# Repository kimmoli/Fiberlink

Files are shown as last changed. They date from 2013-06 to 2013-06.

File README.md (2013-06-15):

Fiberlink
=========

USB <-> 1000µm Fiber <-> RS-232 <-> RS-485

USB <-> RS232
SJ6, SJ7

USB <-> RS485
SJ10, SJ11, SJ15

USB <-> FIBER
SJ3, SJ5

RS232 <-> RS485
SJ12, SJ13, SJ14

RS232 <-> FIBER
SJ2, SJ4

FIBER <-> RS485
SJ8, SJ9, SJ14

SJ2 FIBER RX TO RS232
SJ3 FIBER RX TO USB
SJ4 RS232 RX TO FIBER
SJ5 USB RX TO FIBER
SJ6 USB RX TO RS232
SJ7 RS232 RX TO USB
SJ8 RS485 RX TO FIBER
SJ9 FIBER RX TO RS485
SJ10 RS485 RX TO USB
SJ11 USB RX TO RS485
SJ12 RS232 RX TO RS485
SJ13 RS485 RX TO RS232
SJ14 CARRIER SENSE TO RX485 TXEN
SJ15 USB TXEN TO RS485 TXEN

SJ17 FTDI POWER SELECT

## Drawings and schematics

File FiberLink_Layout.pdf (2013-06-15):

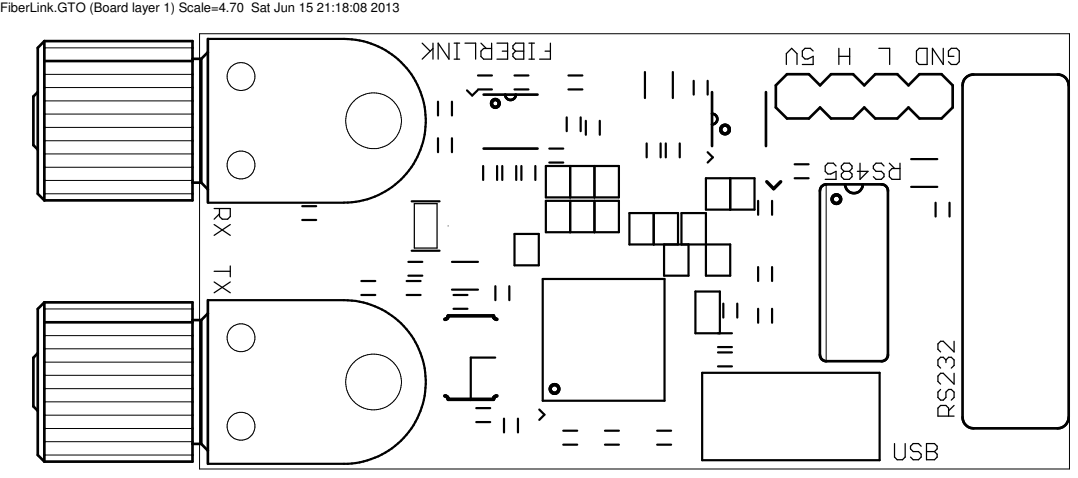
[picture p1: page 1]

FiberLink.GTO (Board layer 1) Scale=4.70 Sat Jun 15 21:18:08 2013

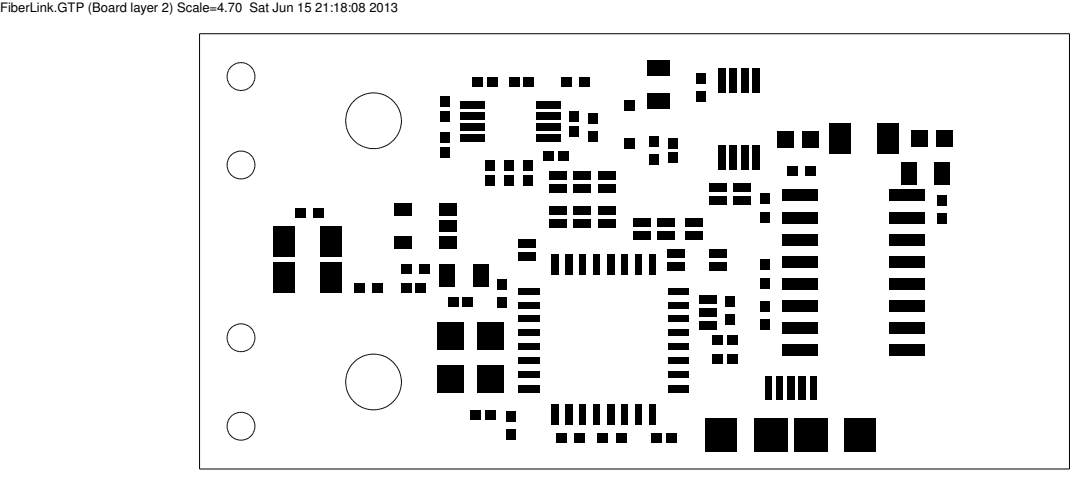
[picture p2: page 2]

FiberLink.GTP (Board layer 2) Scale=4.70 Sat Jun 15 21:18:08 2013

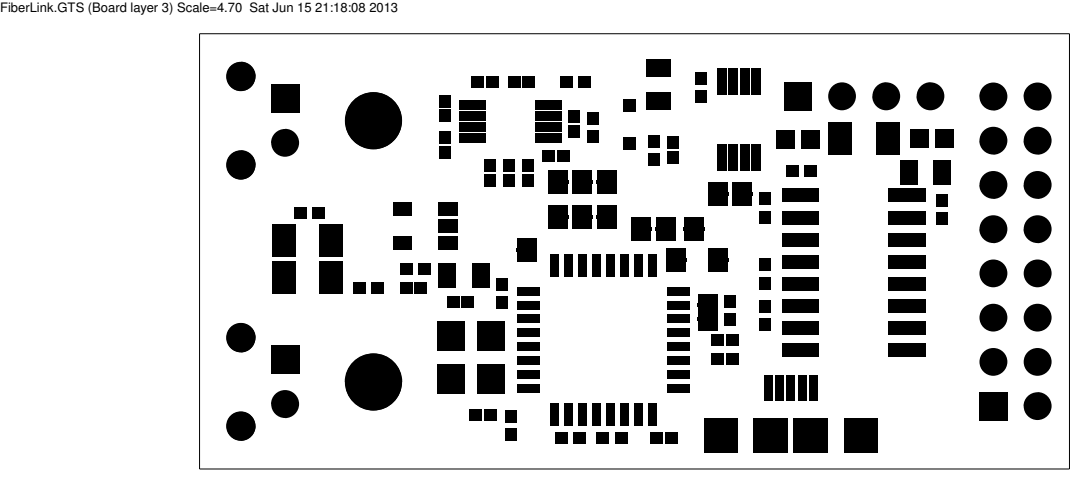
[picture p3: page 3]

FiberLink.GTS (Board layer 3) Scale=4.70 Sat Jun 15 21:18:08 2013

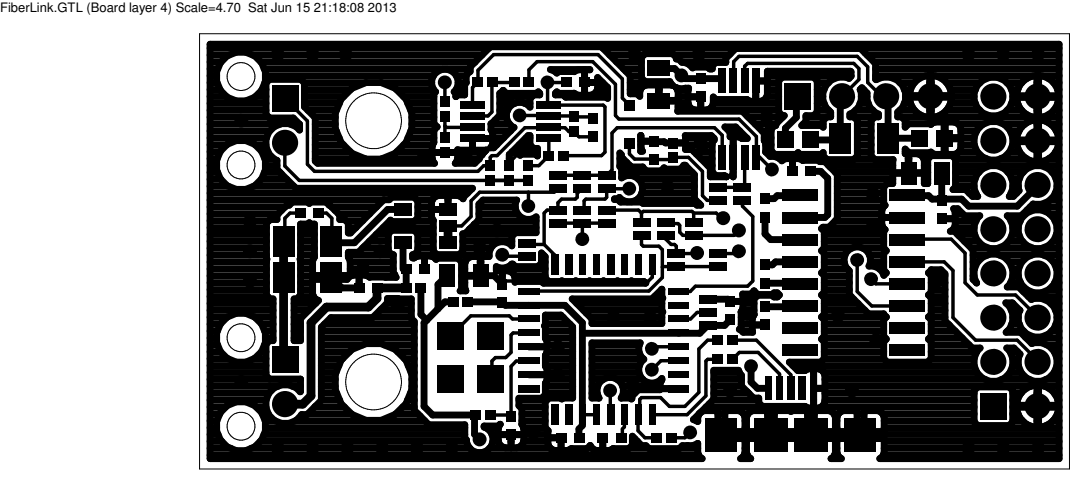
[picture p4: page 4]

FiberLink.GTL (Board layer 4) Scale=4.70 Sat Jun 15 21:18:08 2013

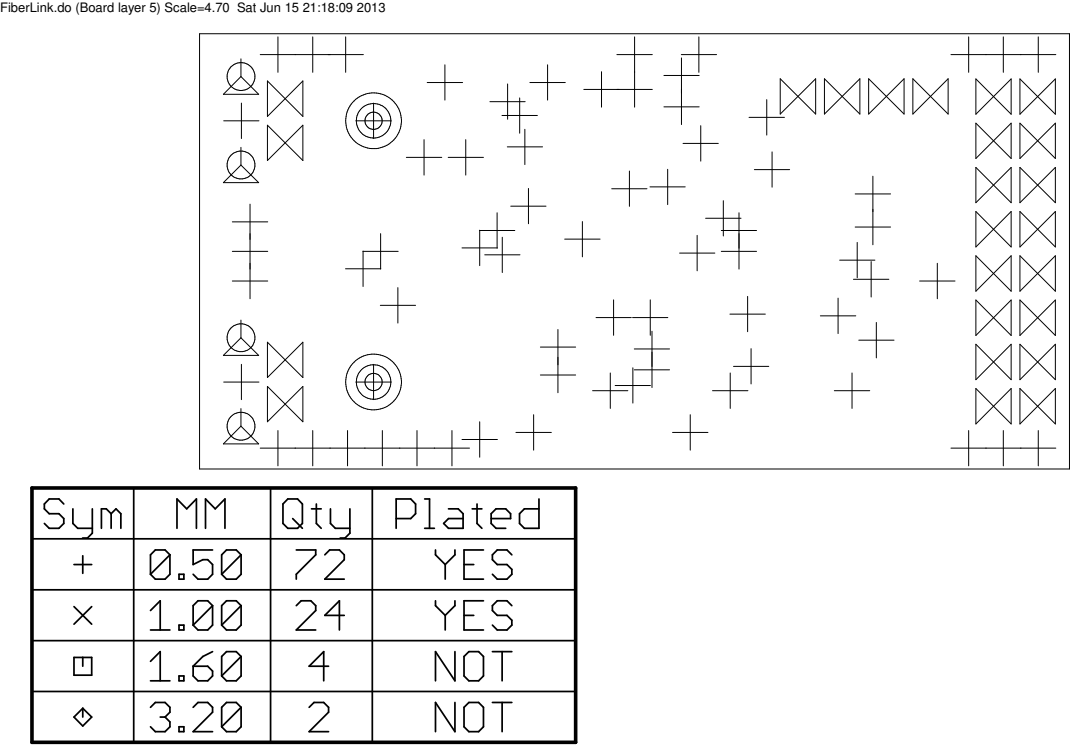
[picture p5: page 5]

FiberLink.do (Board layer 5) Scale=4.70 Sat Jun 15 21:18:09 2013

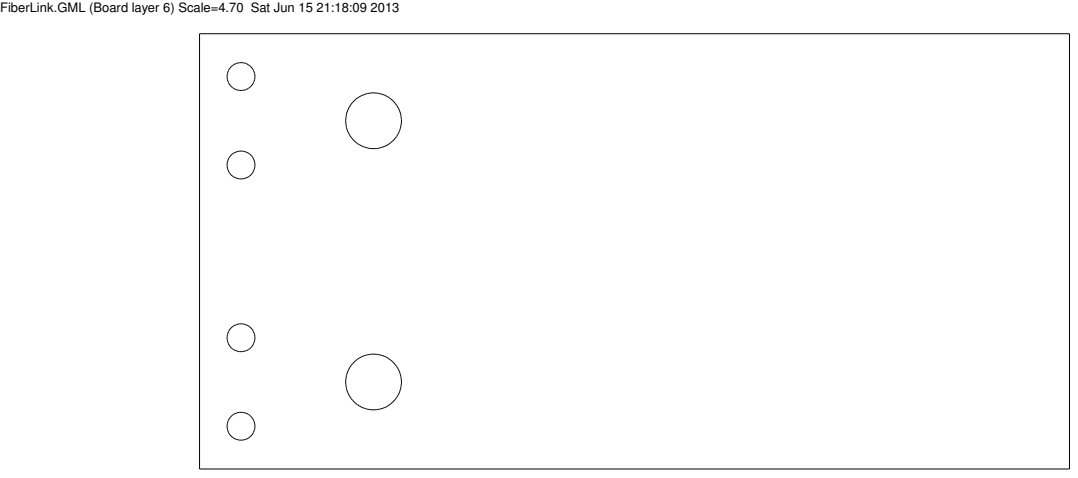
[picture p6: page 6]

FiberLink.GML (Board layer 6) Scale=4.70 Sat Jun 15 21:18:09 2013

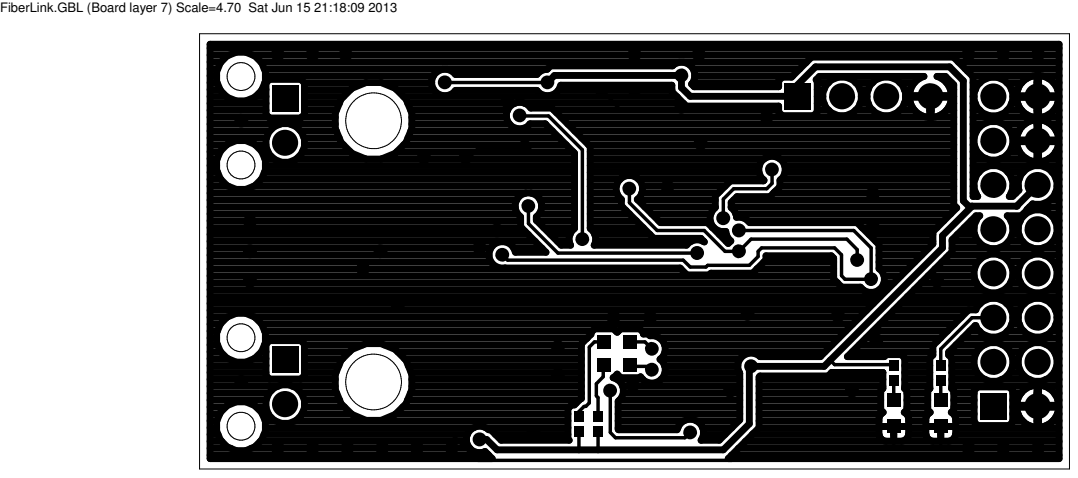
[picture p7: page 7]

FiberLink.GBL (Board layer 7) Scale=4.70 Sat Jun 15 21:18:09 2013

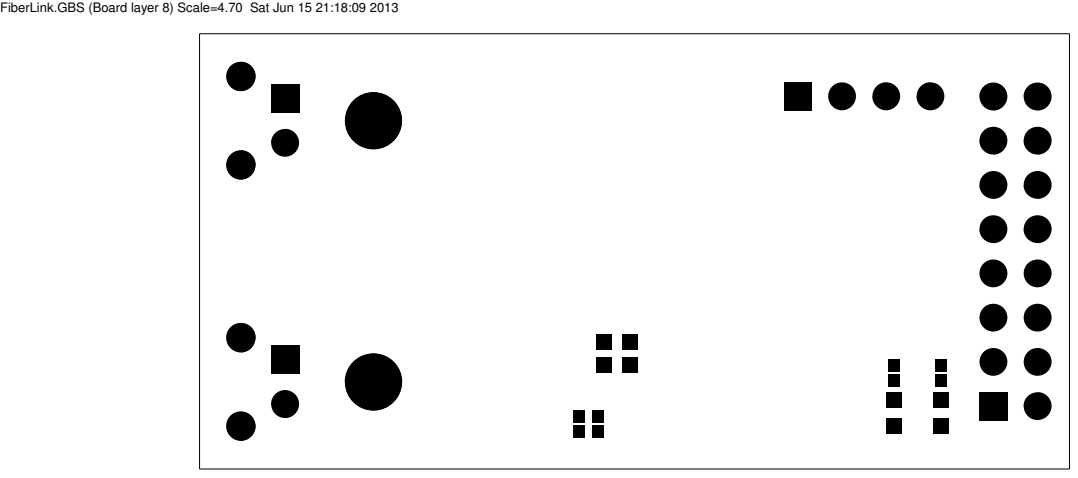
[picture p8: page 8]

FiberLink.GBS (Board layer 8) Scale=4.70 Sat Jun 15 21:18:09 2013

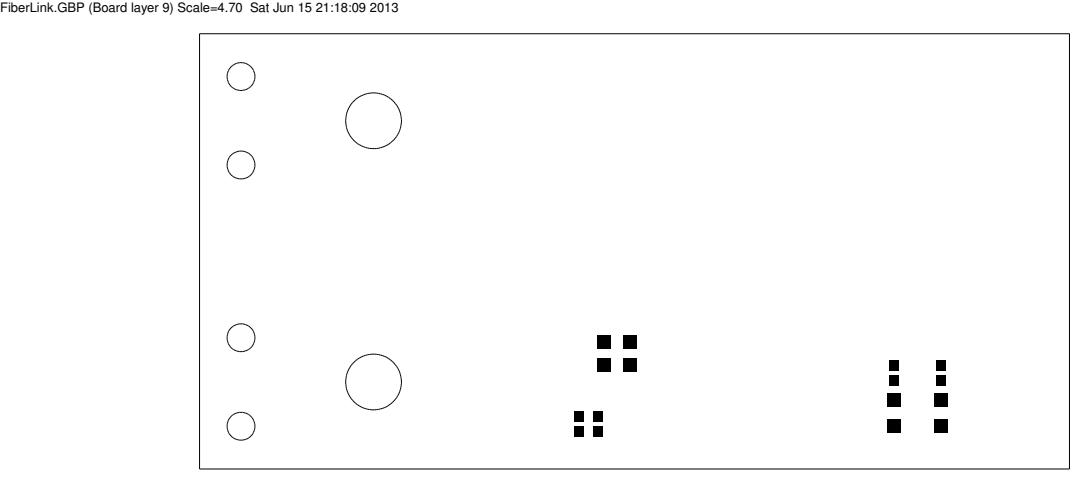
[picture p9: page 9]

FiberLink.GBP (Board layer 9) Scale=4.70 Sat Jun 15 21:18:09 2013

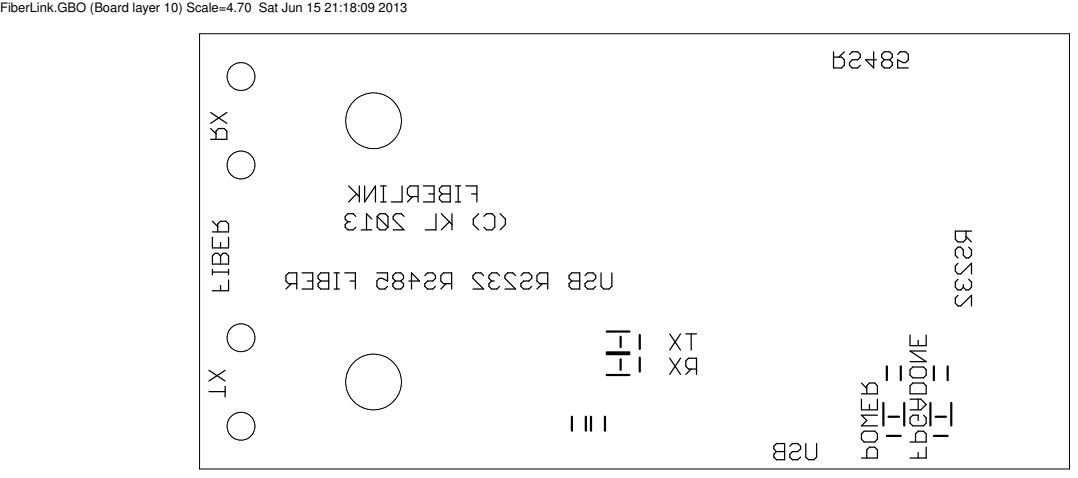
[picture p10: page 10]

FiberLink.GBO (Board layer 10) Scale=4.70 Sat Jun 15 21:18:09 2013

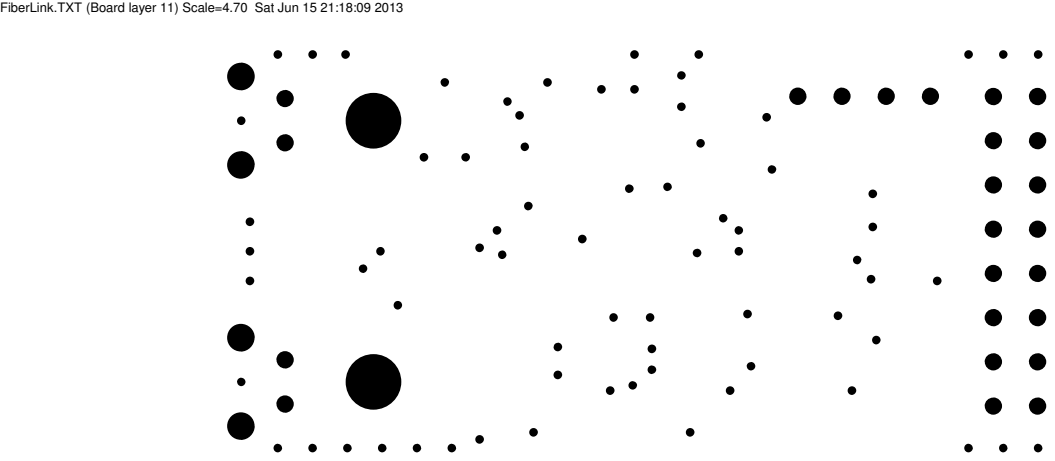
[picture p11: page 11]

FiberLink.TXT (Board layer 11) Scale=4.70 Sat Jun 15 21:18:09 2013

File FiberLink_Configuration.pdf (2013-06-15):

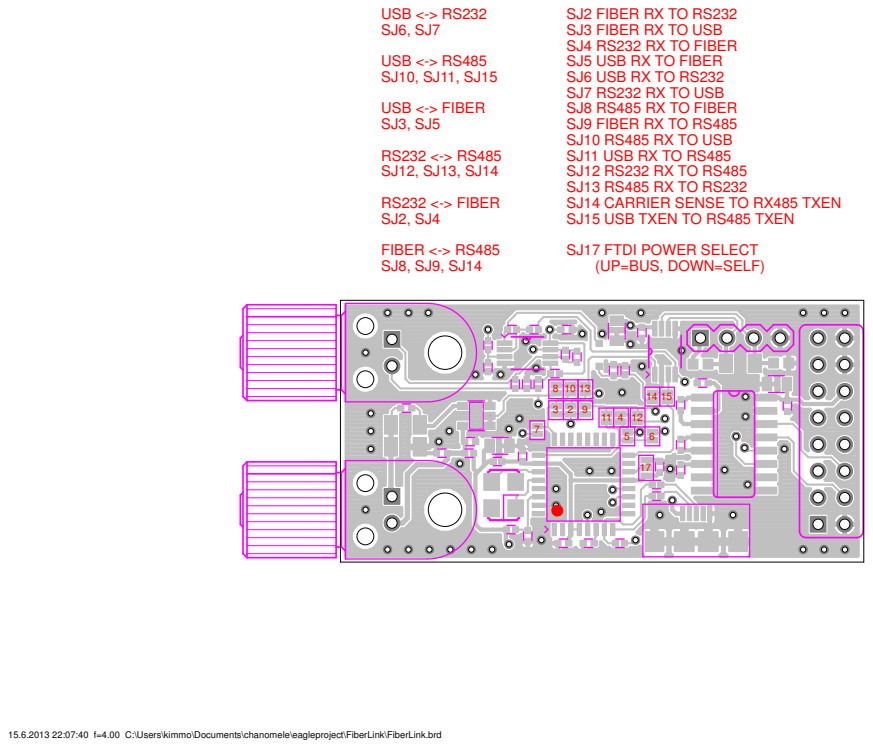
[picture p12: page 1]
USB <-> RS232 SJ6, SJ7; USB <-> RS485 SJ10, SJ11, SJ15; USB <-> FIBER SJ3, SJ5; RS232 <-> FIBER SJ2, SJ4; FIBER <-> RS485 SJ8, SJ9, SJ14

SJ2 FIBER RX TO RS232
SJ3 FIBER RX TO USB
SJ4 RS232 RX TO FIBER
SJ5 USB RX TO FIBER
SJ6 USB RX TO RS232
SJ7 RS232 RX TO USB
SJ8 RS485 RX TO FIBER
SJ9 FIBER RX TO RS485
SJ10 RS485 RX TO USB
SJ11 USB RX TO RS485
SJ14 CARRIER SENSE TO RX485 TXEN
SJ15 USB TXEN TO RS485 TXEN

SJ17 FTDI POWER SELECT
(UP=BUS, DOWN=SELF)

15.6.2013 22:07:40 f=4.00 C:\Users\kimmo\Documents\chanomele\eagleproject\FiberLink\FiberLink.brd

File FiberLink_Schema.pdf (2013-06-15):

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

_RTS 23 _CTS 22 _DTR 21 _DSR 20 _DCD 19 _RI 18 TXDEN 16 | 6

15.6.2013 22:24:45 f=1.14 C:\Users\kimmo\Documents\chanomele\eagleproject\FiberLink\FiberLink.sch (Sheet: 1/1)

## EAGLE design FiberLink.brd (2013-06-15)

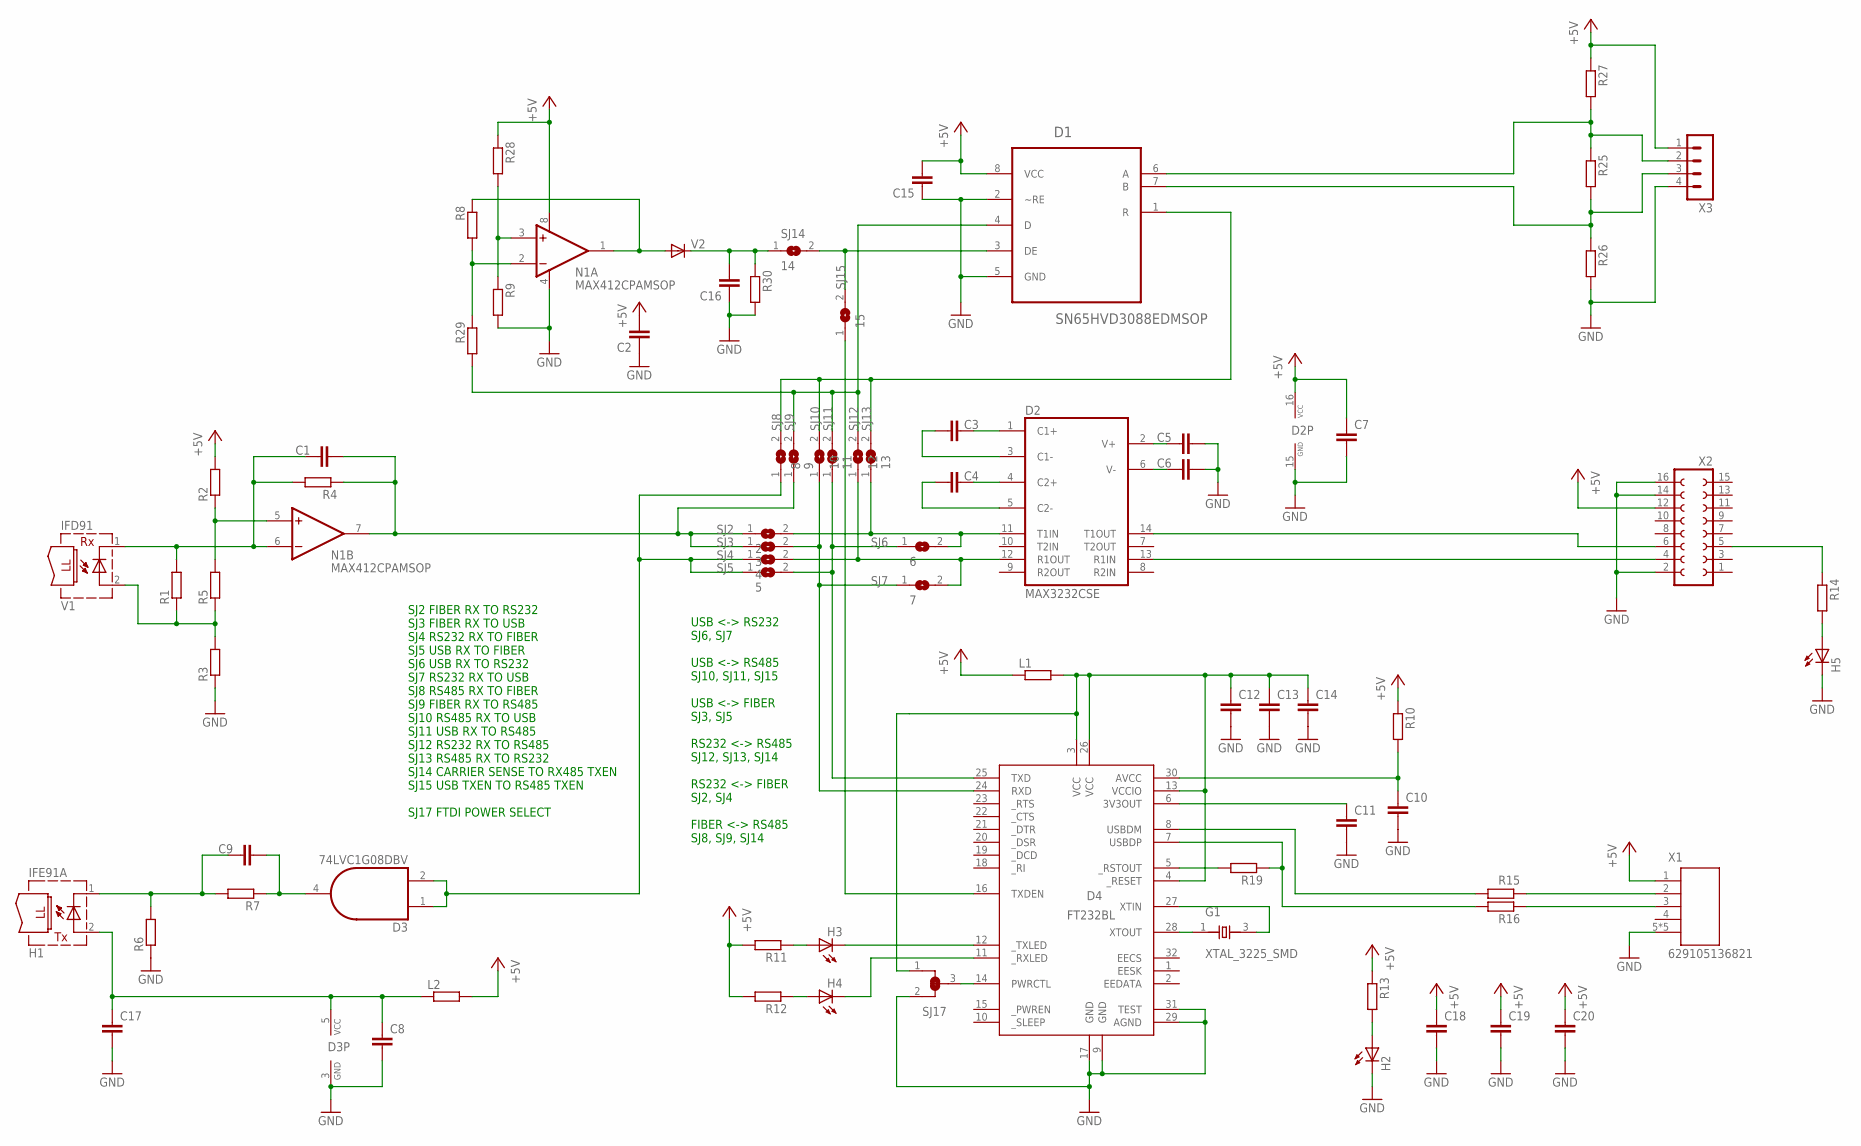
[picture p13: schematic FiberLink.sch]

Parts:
C1, C2, C3, C4, C5, C6, C7, C8, C9, C10, C11, C12, C13, C14, C15, C16, C17: C-EUC0402; C0402
C18, C19, C20: C-EUC0805; C0805
D1: SN65HVD3088EDMSOP; SOP65P490X110-8N
D2: MAX3232CSE; SO16
D3: 74LVC1G08DBV; SOT23-5
D4: FT232BL; LQFP32
G1: XTAL_3225_SMD; X_3225
H1: IFE91A; IFO-IFX
H2, H3, H4, H5: LEDCHIP-LED0603; CHIP-LED0603
L1, L2: R-EU_R0402; R0402_VISHAY
N1: MAX412CPAMSOP; SOP65P490X110-8N
R1, R2, R3, R4, R5, R8, R9, R10, R11, R12, R13, R14, R15, R16, R19, R28, R29, R30: R-EU_R0402; R0402_VISHAY
R6, R7, R25: R-EU_R1206; R1206
R26, R27: R-EU_R0603; R0603
SJ2: 2; SJ-SMALL
SJ3: 3; SJ-SMALL
SJ4: 4; SJ-SMALL
SJ5: 5; SJ-SMALL
SJ6: 6; SJ-SMALL
SJ7: 7; SJ-SMALL
SJ8: 8; SJ-SMALL
SJ9: 9; SJ-SMALL
SJ10: 10; SJ-SMALL
SJ11: 11; SJ-SMALL
SJ12: 12; SJ-SMALL
SJ13: 13; SJ-SMALL
SJ14: 14; SJ-SMALL
SJ15: 15; SJ-SMALL
SJ17: 17; SJ-SMALL-TRI
V1: IFD91; IFO-IFX
V2: DIODE-SOD323-R; SOD323-R
X1: 629105136821
X2: FE08-2
X3: MA04-1

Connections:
485_HIGH: D1.6 (A), R25.1, R27.2, X3.2
485_LOW: D1.7 (B), R25.2, R26.1, X3.3
+5V: C2.2, C7.1, C15.2, C18.1, C19.1, C20.1, D1.8 (VCC), D2.16 (VCC), L1.1, L2.2, N1.8 (V+), R2.2, R10.1, R11.2, R12.2, R13.1, R27.1, R28.1, X1.1, X2.12, X3.1
AVCC: C10.1, D4.30 (AVCC), R10.2
CARRIER_SENSE: C16.2, R30.1, SJ14.1, V2.C
FPGADONE: R14.1, X2.5
G1: D4.27 (XTIN), G1.3 (X2)
GND: C2.1, C5.2, C6.2, C7.2, C8.2, C10.2, C11.2, C12.2, C13.2, C14.2, C15.1, C16.1, C17.2, C18.2, C19.2, C20.2, D1.2 (~RE), D1.5 (GND), D2.15 (GND), D3.3 (GND), D4.9 (GND), D4.17 (GND), D4.29 (AGND), D4.31 (TEST), H2.C, H5.C, N1.4 (V-), R3.1, R6.1, R9.2, R26.2, R30.2, SJ17.2, X1.5, X1.Z1 (5), X1.Z2 (5), X1.Z3 (5), X1.Z4 (5), X2.2, X2.14, X2.16, X3.4
unnamed: C1.1, N1.6 (-IN), R1.2, R4.2, V1.1 (C)
unnamed: N1.1 (OUT), R8.1, V2.A
unnamed: R1.1, R3.2, R5.1, V1.2 (A)
unnamed: D4.12 (_TXLED), H3.C
unnamed: N1.5 (+IN), R2.1, R5.2
unnamed: C4.2, D2.5 (C2-)
unnamed: C4.1, D2.4 (C2+)
unnamed: C3.2, D2.3 (C1-)
unnamed: C3.1, D2.1 (C1+)
unnamed: C6.1, D2.6 (V-)
unnamed: C5.1, D2.2 (V+)
unnamed: D2.14 (T1OUT), X2.6
unnamed: D2.13 (R1IN), X2.4
unnamed: D4.11 (_RXLED), H4.C
unnamed: C9.1, H1.1 (C), R6.2, R7.2
unnamed: N1.3 (+IN), R9.1, R28.2
unnamed: C9.2, D3.4 (O), R7.1
unnamed: H3.A, R11.1
unnamed: R15.1, X1.2
unnamed: H4.A, R12.1
unnamed: D4.8 (USBDM), R15.2
unnamed: H2.A, R13.2
unnamed: D4.7 (USBDP), R16.2, R19.1
unnamed: R16.1, X1.3
unnamed: H5.A, R14.2
unnamed: D4.14 (PWRCTL), SJ17.3
unnamed: D4.5 (_RSTOUT), R19.2
unnamed: N1.2 (-IN), R8.2, R29.1
unnamed: D4.28 (XTOUT), G1.1 (X1)
RXD_232: D2.12 (R1OUT), SJ4.2, SJ7.2, SJ12.1
RXD_485: D1.1 (R), SJ8.2, SJ10.2, SJ13.2
RXD_FIBER: C1.2, N1.7 (OUT), R4.1, SJ2.1, SJ3.1, SJ9.1
RXD_USB: D4.24 (RXD), SJ3.2, SJ7.1, SJ10.1
TXD_232: D2.11 (T1IN), SJ2.2, SJ6.2, SJ13.1
TXD_485: D1.4 (D), R29.2, SJ9.2, SJ11.2, SJ12.2
TXD_FIBER: D3.1 (I0), D3.2 (I1), SJ4.1, SJ5.1, SJ8.1
TXD_USB: D4.25 (TXD), SJ5.2, SJ6.1, SJ11.1
TXEN_485: D1.3 (DE), SJ14.2, SJ15.2
TXEN_USB: D4.16 (TXDEN), SJ15.1
TX_VCC: C8.1, C17.1, D3.5 (VCC), H1.2 (A), L2.1
USB3V3: C11.1, D4.6 (3V3OUT)
USBVCC: C12.1, C13.1, C14.1, D4.3 (VCC), D4.4 (_RESET), D4.13 (VCCIO), D4.26 (VCC), L1.2, SJ17.1

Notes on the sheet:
SJ2 FIBER RX TO RS232 SJ3 FIBER RX TO USB SJ4 RS232 RX TO FIBER SJ5 USB RX TO FIBER SJ6 USB RX TO RS232 SJ7 RS232 RX TO USB SJ8 RS485 RX TO FIBER SJ9 FIBER RX TO RS485 SJ10 RS485 RX TO USB SJ11 USB RX TO RS485 SJ12 RS232 RX TO RS485 SJ13 RS485 RX TO RS232 SJ14 CARRIER SENSE TO RX485 TXEN SJ15 USB T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
USB <-> RS232 SJ6, SJ7 USB <-> RS485 SJ10, SJ11, SJ15 USB <-> FIBER SJ3, SJ5 RS232 <-> RS485 SJ12, SJ13, SJ14 RS232 <-> FIBER SJ2, SJ4 FIBER <-> RS485 SJ8, SJ9, SJ14

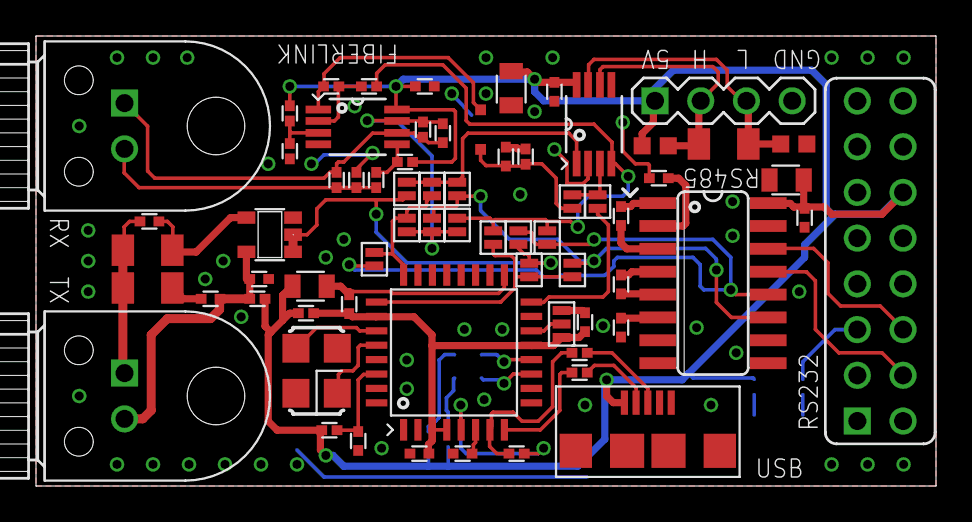
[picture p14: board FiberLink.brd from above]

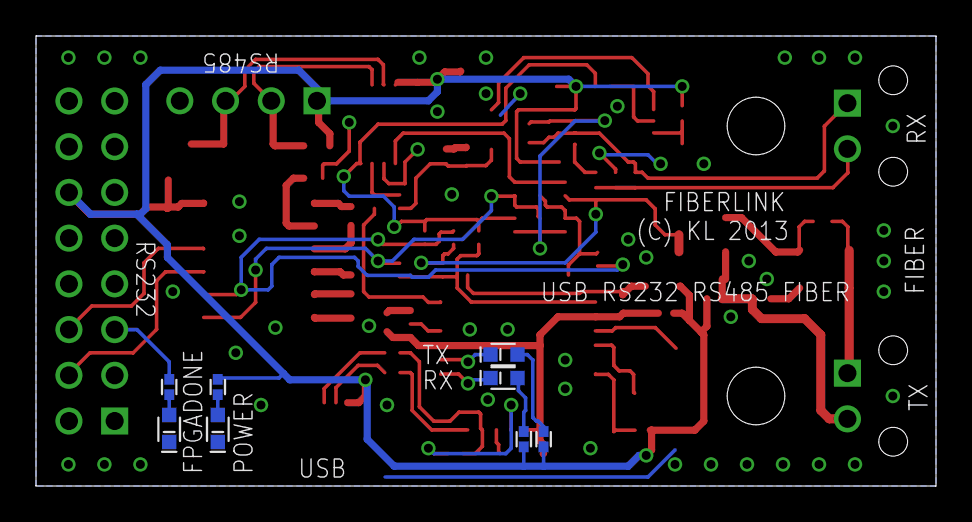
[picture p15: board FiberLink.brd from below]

Board: 2 copper layers, 50.0 x 25.0 mm, 77 parts (8 on the bottom side), 50 nets.

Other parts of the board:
DRILEGEND: DRILEGEND

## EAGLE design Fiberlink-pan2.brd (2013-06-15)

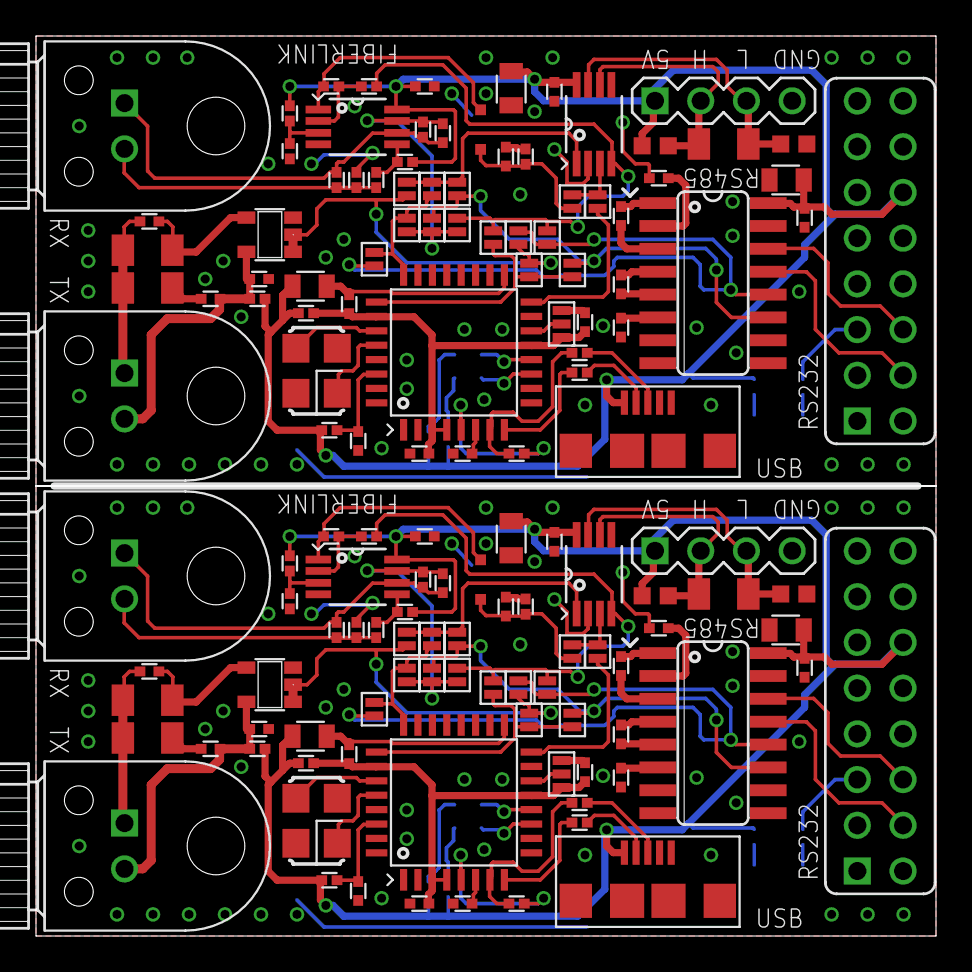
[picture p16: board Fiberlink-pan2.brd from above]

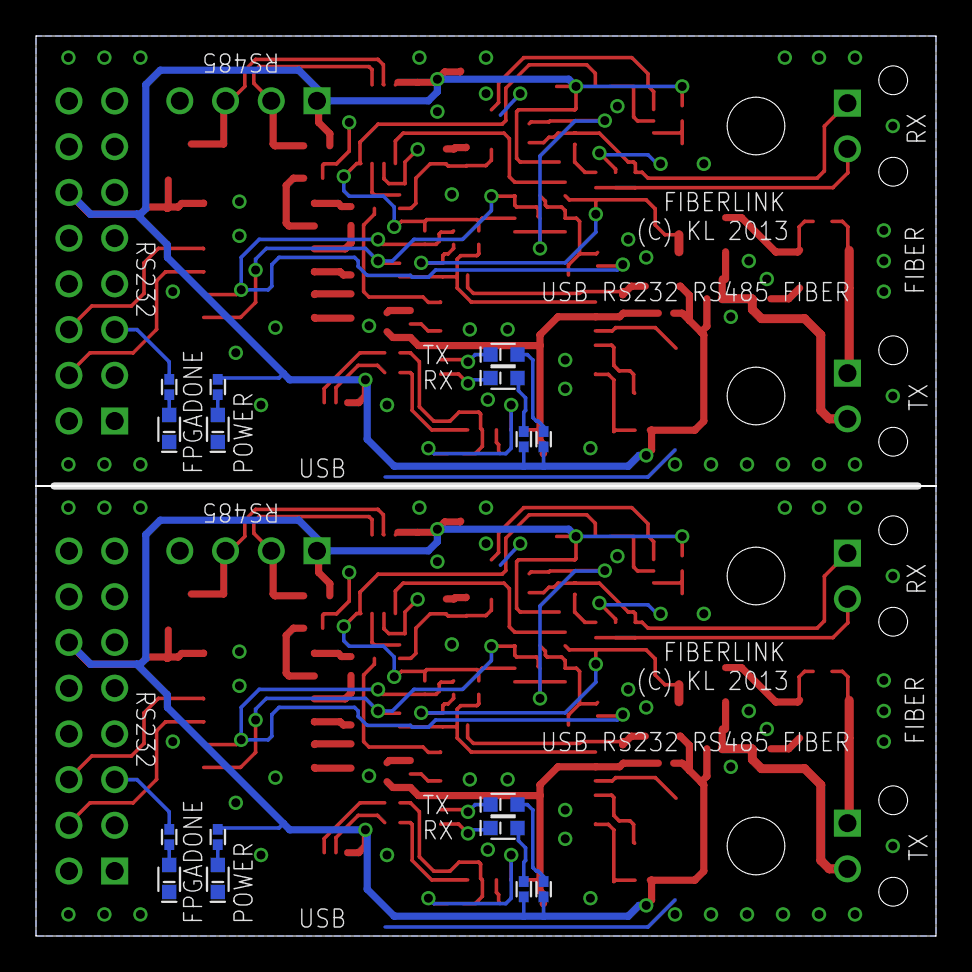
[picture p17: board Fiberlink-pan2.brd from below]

Board: 2 copper layers, 50.0 x 50.0 mm, 153 parts (16 on the bottom side), 100 nets.

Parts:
C1, C2, C3, C4, C5, C6, C7, C8, C9, C10, C11, C12, C13, C14, C15, C16, C17, C21, C22, C23, C24, C25, C26, C27, C28, C29, C30, C31, C32, C33, C34, C35, C36, C37: C0402
C18, C19, C20, C38, C39, C40: C0805
D1, D8: SN65HVD3088EDMSOP; SOP65P490X110-8N
D2, D5: MAX3232CSE; SO16
D3, D6: 74LVC1G08DBV; SOT23-5
D4, D7: FT232BL; LQFP32
DRILEGEND: DRILEGEND
G1, G2: XTAL_3225_SMD; X_3225
H1, H6: IFE91A; IFO-IFX
H2, H3, H4, H5, H7, H8, H9, H10: CHIP-LED0603
L1, L2, L3, L4: R0402_VISHAY
N1, N2: MAX412CPAMSOP; SOP65P490X110-8N
R1, R2, R3, R4, R5, R8, R9, R10, R11, R12, R13, R14, R15, R16, R17, R18, R19, R20, R21, R22, R28, R29, R30, R31, R32, R33, R34, R35, R36, R40, R41, R42, R43, R44, R45, R46: R0402_VISHAY
R6, R7, R23, R24, R25, R37: R1206
R26, R27, R38, R39: R0603
SJ1, SJ2, SJ3, SJ4, SJ5, SJ6, SJ7, SJ8, SJ9, SJ10, SJ11, SJ12, SJ13, SJ14, SJ15, SJ16, SJ18, SJ19, SJ20, SJ21, SJ22, SJ23, SJ24, SJ25, SJ26, SJ27, SJ28, SJ29: SJ-SMALL
SJ17, SJ30: SJ-TRI; SJ-SMALL-TRI
V1, V4: IFD91; IFO-IFX
V2, V3: SOD323-R
X1, X5: 629105136821
X2, X4: FE08-2
X3, X6: MA04-1

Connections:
485_HIGH: D1.6, R25.1, R27.2, X3.2
485_HIGH1: D8.6, R37.1, R39.2, X6.2
485_LOW: D1.7, R25.2, R26.1, X3.3
485_LOW1: D8.7, R37.2, R38.1, X6.3
+5V: C2.2, C7.1, C15.2, C18.1, C19.1, C20.1, D1.8, D2.16, L1.1, L2.2, N1.8, R2.2, R10.1, R11.2, R12.2, R13.1, R27.1, R28.1, X1.1, X2.12, X3.1
+5V1: C22.2, C27.1, C35.2, C38.1, C39.1, C40.1, D5.16, D8.8, L3.1, L4.2, N2.8, R18.2, R33.1, R39.1, R40.1, R43.2, R44.2, R45.1, X4.12, X5.1, X6.1
AVCC: C10.1, D4.30, R10.2
AVCC1: C30.1, D7.30, R33.2
CARRIER_SENSE: C16.2, R30.1, SJ14.1, V2.C
CARRIER_SENSE1: C36.2, R42.1, SJ28.1, V3.C
FPGADONE: R14.1, X2.5
FPGADONE1: R46.1, X4.5
G1: D4.27, G1.3
G2: D7.27, G2.3
GND: C2.1, C5.2, C6.2, C7.2, C8.2, C10.2, C11.2, C12.2, C13.2, C14.2, C15.1, C16.1, C17.2, C18.2, C19.2, C20.2, D1.2, D1.5, D2.15, D3.3, D4.9, D4.17, D4.29, D4.31, H2.C, H5.C, N1.4, R3.1, R6.1, R9.2, R26.2, R30.2, SJ17.2, X1.5, X1.Z1, X1.Z2, X1.Z3, X1.Z4, X2.2, X2.14, X2.16, X3.4
GND1: C22.1, C25.2, C26.2, C27.2, C28.2, C30.2, C31.2, C32.2, C33.2, C34.2, C35.1, C36.1, C37.2, C38.2, C39.2, C40.2, D5.15, D6.3, D7.9, D7.17, D7.29, D7.31, D8.2, D8.5, H9.C, H10.C, N2.4, R20.1, R23.1, R32.2, R38.2, R42.2, SJ30.2, X4.2, X4.14, X4.16, X5.5, X5.Z1, X5.Z2, X5.Z3, X5.Z4, X6.4
unnamed: C1.1, N1.6, R1.2, R4.2, V1.1
unnamed: N1.1, R8.1, V2.A
unnamed: R1.1, R3.2, R5.1, V1.2
unnamed: D4.12, H3.C
unnamed: N1.5, R2.1, R5.2
unnamed: C4.2, D2.5
unnamed: C4.1, D2.4
unnamed: C3.2, D2.3
unnamed: C3.1, D2.1
unnamed: C6.1, D2.6
unnamed: C5.1, D2.2
unnamed: D2.14, X2.6
unnamed: D2.13, X2.4
unnamed: D4.11, H4.C
unnamed: C9.1, H1.1, R6.2, R7.2
unnamed: N1.3, R9.1, R28.2
unnamed: C9.2, D3.4, R7.1
unnamed: H3.A, R11.1
unnamed: R15.1, X1.2
unnamed: H4.A, R12.1
unnamed: D4.8, R15.2
unnamed: H2.A, R13.2
unnamed: D4.7, R16.2, R19.1
unnamed: R16.1, X1.3
unnamed: H5.A, R14.2
unnamed: D4.14, SJ17.3
unnamed: C21.1, N2.6, R17.2, R21.2, V4.1
unnamed: R17.1, R20.2, R22.1, V4.2
unnamed: D4.5, R19.2
unnamed: N2.5, R18.1, R22.2
unnamed: C24.2, D5.5
unnamed: N1.2, R8.2, R29.1
unnamed: D4.28, G1.1
unnamed: C24.1, D5.4
unnamed: C23.2, D5.3
unnamed: C23.1, D5.1
unnamed: C26.1, D5.6
unnamed: C25.1, D5.2
unnamed: D5.14, X4.6
unnamed: C29.1, H6.1, R23.2, R24.2
unnamed: C29.2, D6.4, R24.1
unnamed: N2.1, R31.1, V3.A
unnamed: N2.3, R32.1, R40.2
unnamed: R34.1, X5.2
unnamed: D7.8, R34.2
unnamed: D7.7, R35.2, R36.1
unnamed: R35.1, X5.3
unnamed: D7.5, R36.2
unnamed: D7.28, G2.1
unnamed: D5.13, X4.4
unnamed: N2.2, R31.2, R41.1
unnamed: D7.12, H7.C
unnamed: D7.11, H8.C
unnamed: H7.A, R43.1
unnamed: H8.A, R44.1
unnamed: H9.A, R45.2
unnamed: H10.A, R46.2
unnamed: D7.14, SJ30.3
RXD_1: D5.12, SJ18.2, SJ21.2, SJ26.1
RXD_2: D8.1, SJ22.2, SJ24.2, SJ27.2
RXD_232: D2.12, SJ4.2, SJ7.2, SJ12.1
RXD_485: D1.1, SJ8.2, SJ10.2, SJ13.2
RXD_FIBER: C1.2, N1.7, R4.1, SJ2.1, SJ3.1, SJ9.1
RXD_FIBER1: C21.2, N2.7, R21.1, SJ1.1, SJ16.1, SJ23.1
RXD_USB: D4.24, SJ3.2, SJ7.1, SJ10.1
RXD_USB1: D7.24, SJ16.2, SJ21.1, SJ24.1
TXD_1: D5.11, SJ1.2, SJ20.2, SJ27.1
TXD_2: D8.4, R41.2, SJ23.2, SJ25.2, SJ26.2
TXD_232: D2.11, SJ2.2, SJ6.2, SJ13.1
TXD_485: D1.4, R29.2, SJ9.2, SJ11.2, SJ12.2
TXD_FIBER: D3.1, D3.2, SJ4.1, SJ5.1, SJ8.1
TXD_FIBER1: D6.1, D6.2, SJ18.1, SJ19.1, SJ22.1
TXD_USB: D4.25, SJ5.2, SJ6.1, SJ11.1
TXD_USB1: D7.25, SJ19.2, SJ20.1, SJ25.1
TXEN_1: D8.3, SJ28.2, SJ29.2
TXEN_485: D1.3, SJ14.2, SJ15.2
TXEN_USB: D4.16, SJ15.1
TXEN_USB1: D7.16, SJ29.1
TX_VCC: C8.1, C17.1, D3.5, H1.2, L2.1
TX_VCC1: C28.1, C37.1, D6.5, H6.2, L4.1
USB3V1: C31.1, D7.6
USB3V3: C11.1, D4.6
USBVCC: C12.1, C13.1, C14.1, D4.3, D4.4, D4.13, D4.26, L1.2, SJ17.1
USBVCC1: C32.1, C33.1, C34.1, D7.3, D7.4, D7.13, D7.26, L3.2, SJ30.1

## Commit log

2013-06-15 changed passive packages
    [FiberLink_RS232.brd, FiberLink_RS232.sch]
2013-06-15 first completely routed
    [FiberLink_RS232.brd, FiberLink_RS232.sch]
2013-06-15 Added some leds
    [FiberLink_RS232.brd, FiberLink_RS232.sch]
2013-06-15 New filenames
    [FiberLink.brd, FiberLink.sch]
2013-06-15 Panelisation added. Corrected drill sizes
    [FiberLink.sch, Fiberlink-pan2.brd]
2013-06-15 PDF Schematic added
2013-06-15 PDF Layout added
    [FiberLink.brd]
2013-06-15 Configuration documentation added
    [FiberLink.brd, FiberLink.sch]
